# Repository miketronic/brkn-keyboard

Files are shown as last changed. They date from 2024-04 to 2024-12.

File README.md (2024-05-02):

# BR/KN
BR/KN Keyboard (Broken)




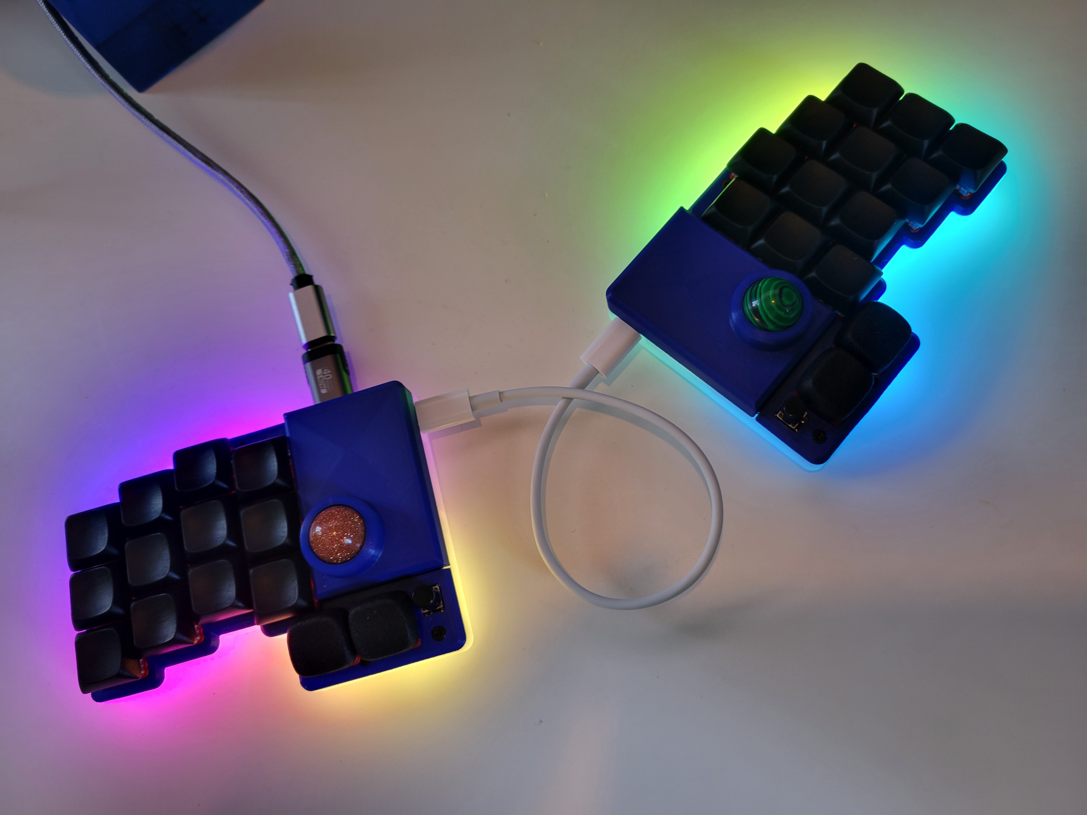
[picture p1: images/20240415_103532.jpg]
BR/KN 001

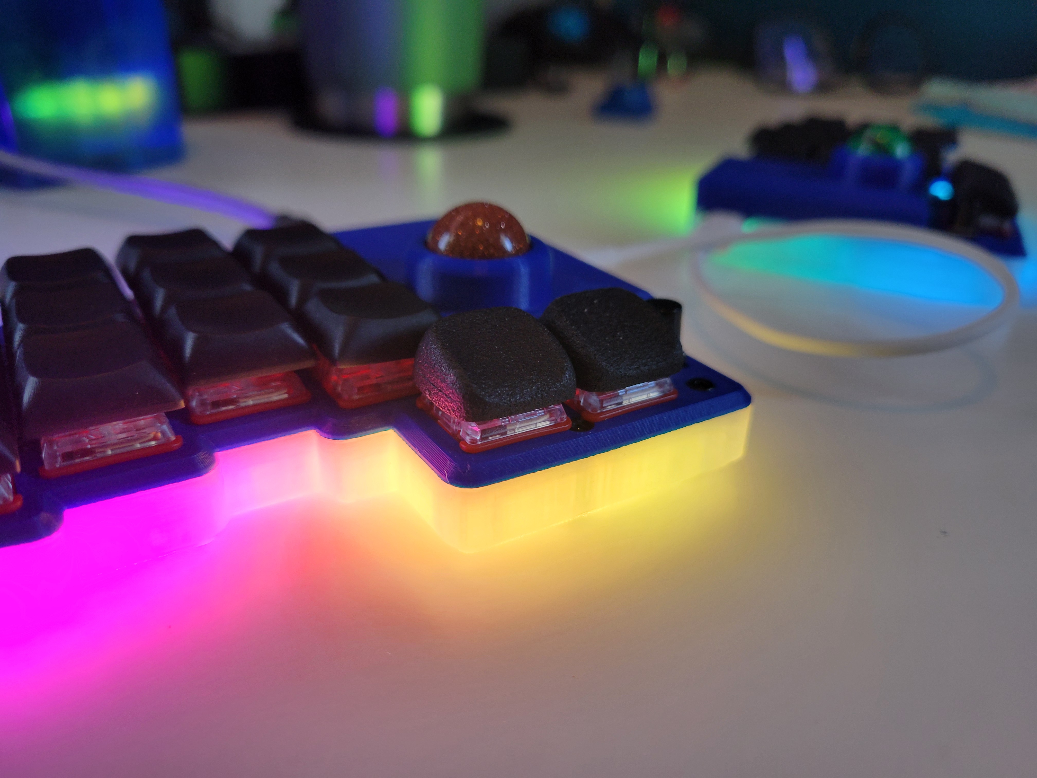
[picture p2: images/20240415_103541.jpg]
BR/KN 002


[More pictures here](images/)

## Features

- 28 keys (plus 2 small tactiles, bonus!)
- 2x 16mm trackballs - PMW3360 sensors
- USB connection between halves (or TRRS option as backup)
- Low profile choc switches with CFX spacing (closer spacing then standard choc, only caps of size 16.50mm x 16.50mm will fit)
- RGB lighting
- Waveshare RP2040 Zero controllers
- QMK firmware

## Introduction

The Broken (stylized BR/KN) keyboard is named because... 

  1. it's a split (a broken unibody)
  2. Broken by Seether was my wife and mine's wedding song that I wanted to honor and the day (queue awww's).  Ok enough on that, let's dig in.

I've always preferred small keebs and low switch counts.  The idea for this keyboard was to design a small split that also incorporated two trackballs (can use one for pointing, one for scrolling!), and have some other goodies like LEDs and tact switches for occasional needs like macros or toggling the RGB.

## Keymap

The layout is a larger rendition of my MM20 (3 column) layout with the addition of side columms.  I have no issues with my 20 key layout but it's a BIG change for users and having some keys like tab and backspace on dedicated keys can be convenient.  Of course with custom firmware you are not locked into any specific layout.  If you only want to combo 2 letters (24 non-thumb keys, 26 letters!), then that's totally fine.

The layout, MM28, leverages combos (the yellow letters shown below) for less-used letters, or where they "feel best".  I performed some studies on letter frequency in the English language and most common bigrams and trigrams to determine the letter placement. It kind of started off as Colemak from what I recall, maybe it's actually really different, I forgets.  P and B are weird, they both just barely made it to combos instead of their own letters even though I use them more often then I anticipated.  They could have gone somewhere like the U and W keys but with the frequency I use them I wanted them on my index and middle finger instead of putting all that work on my ring finger.

The biggest thing with starting a layout like this is to accept the fact that you'll start off at like 5wpm but your brain will take over and it'll become second nature eventually just like any other layout.  It's super fun and not making any lateral finger movements feels nice. 

br-kn

## Keycaps

As noted in the *Features*, I chose a narrower keyswitch spacing and thus they require narrower keycaps.  CFX keycaps are commercially available from Chosfox, or you can print your own, for which I've included files in the keycaps folder.  They easily print upside down on an FDM printer, and I use a textured baseplate.

## Miscellaneous Notes

- For the switchplate, I put the plate on then soldered the switches.  Make sure you like your choice of filament that you printed the plate with because you're stuck with it ;).
- If you PCBA the board and the USB failed during manufacture, you can solder on a TRRS connector.  I have it designed to mount the TRRS on the bottom of the board to hide the connector and end of the cable within the case.  Also, you'll need to bodge two wires on the board to use TRRS, let me know if you need help if you go this route.
- The trackballs I used are 16mm polished mineral spheres I found on AliExpress.  I picked up a few different types of mineral and some were too large due to making a rock into a sphere not an exact science, so be mindful of that.  Alternatively, you can use human-made materials for a perfect spec 16mm ball.
- PCBA would be cheaper if you combine both halves with some mouse bites between them, feel free to do so or modify as you wish.  I did this version as a POC so it was cheaper if I messed up with one board than with both at the same time.

## The predecessor (CAP 5)

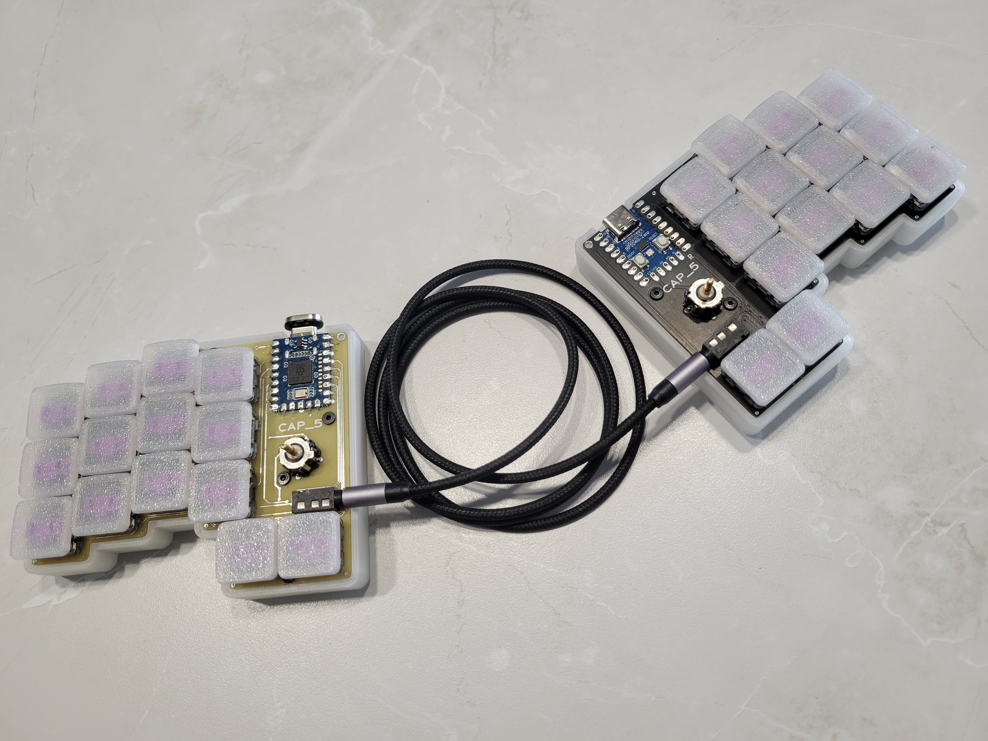
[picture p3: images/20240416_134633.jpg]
CAP5 001


[Another shot](images/20240416_134642.jpg)

Contact with comments, questions, or if you build it!
- m1ketronic @discord
- mxb540@gmail.com

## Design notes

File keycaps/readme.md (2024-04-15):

### Print these face down. They feel nicer with a textured build plate.

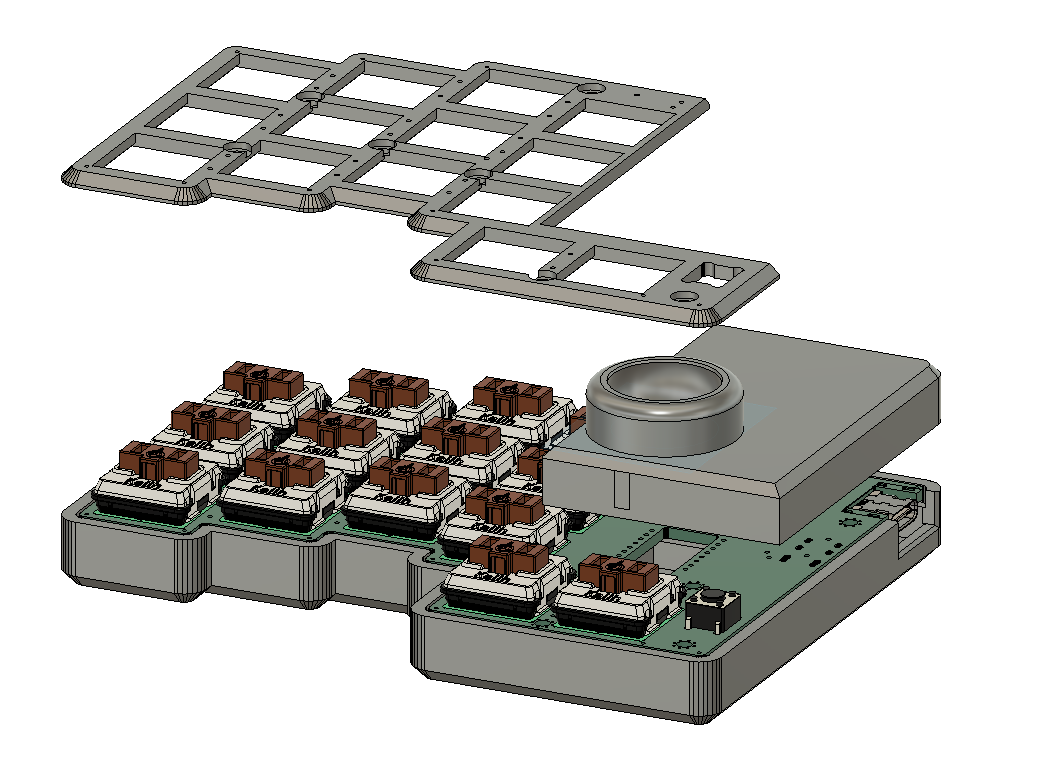
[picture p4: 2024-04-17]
images/brkn_guts.png

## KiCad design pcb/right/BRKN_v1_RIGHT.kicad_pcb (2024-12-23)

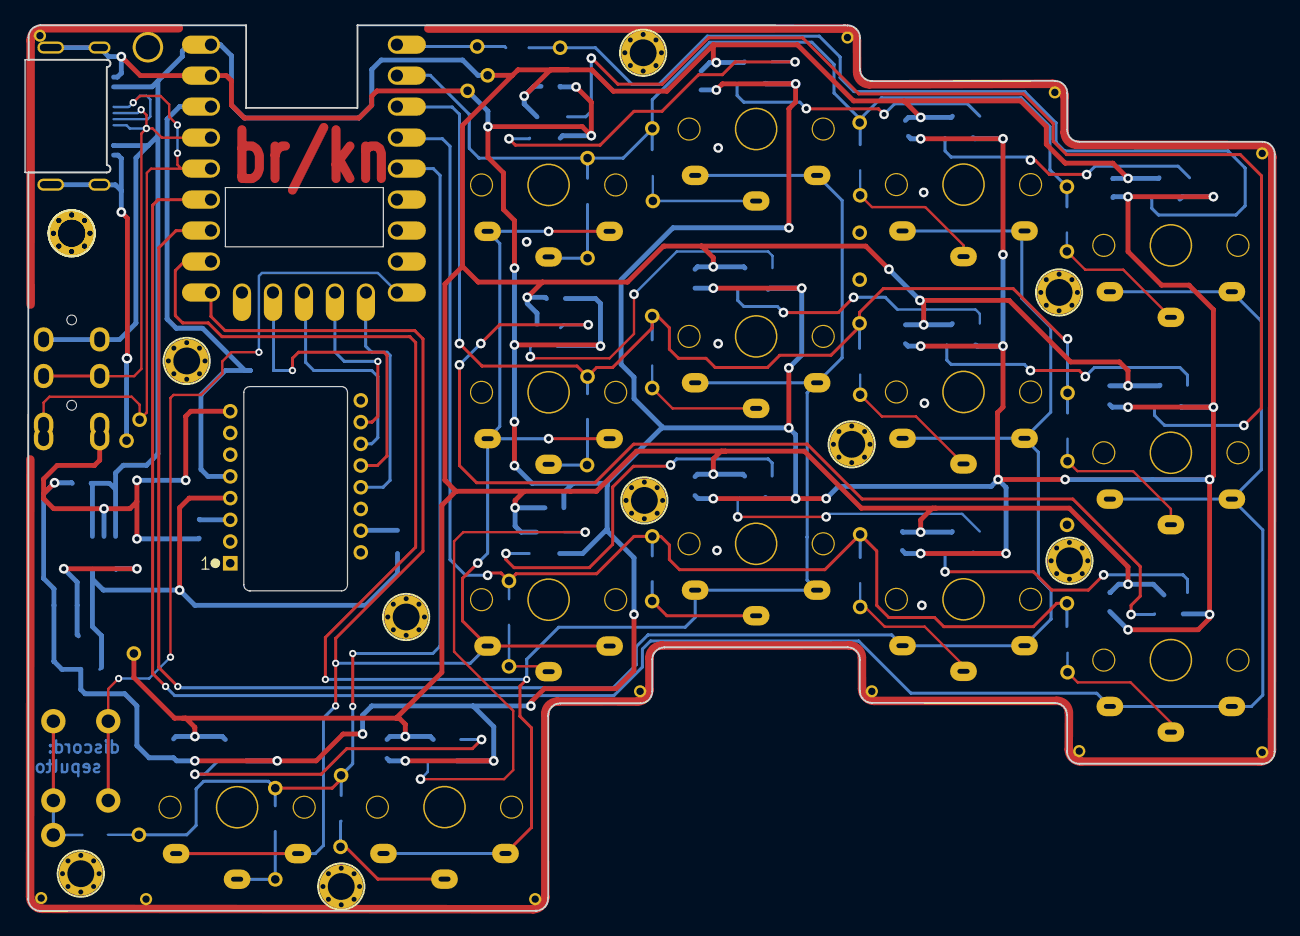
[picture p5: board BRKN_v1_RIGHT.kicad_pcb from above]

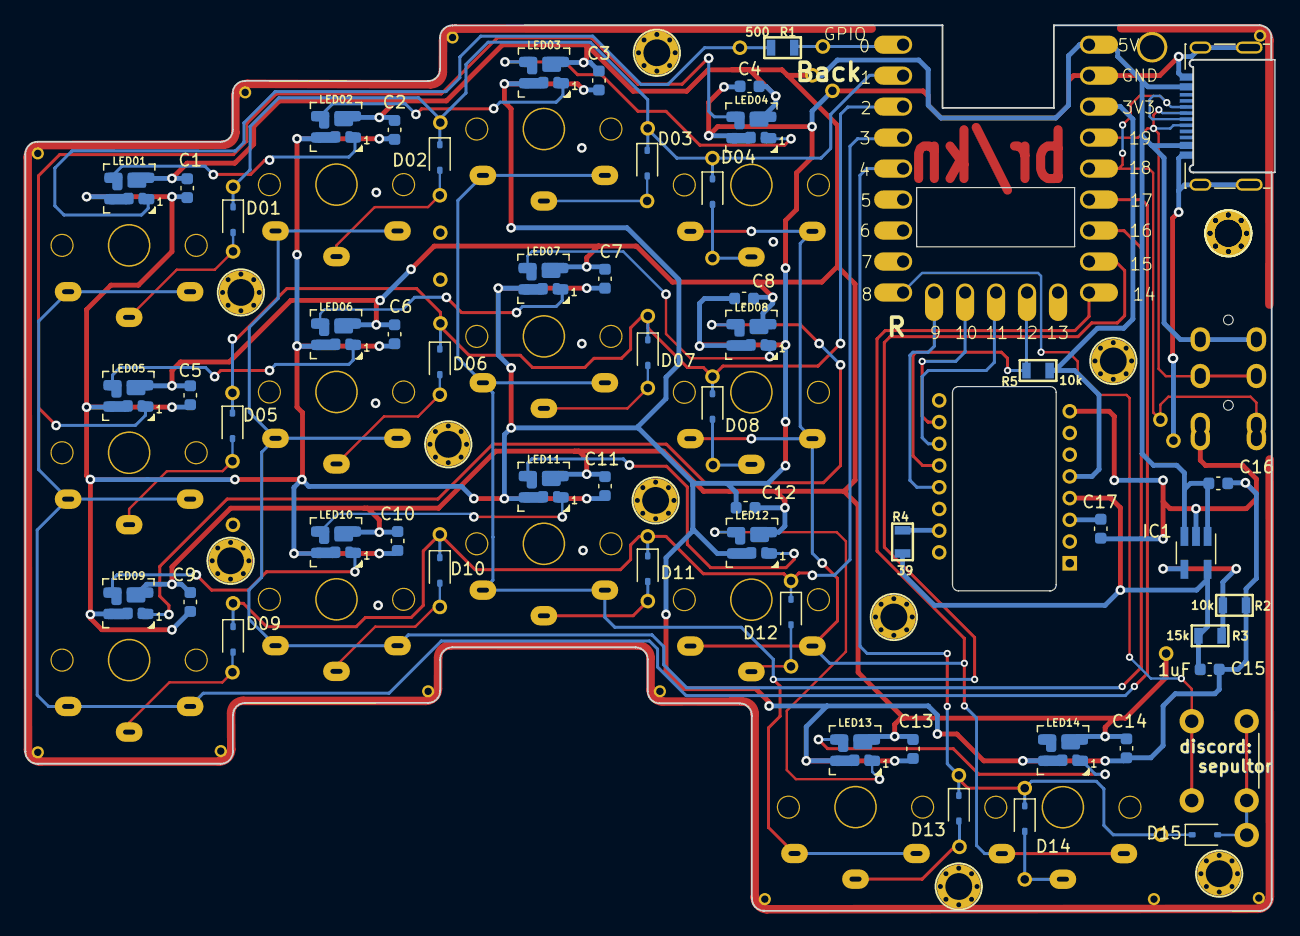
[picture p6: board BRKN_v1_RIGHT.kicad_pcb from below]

Board: 2 copper layers, 102.2 x 72.6 mm, 71 parts (69 on the bottom side), 52 nets.

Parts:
C1, C2, C3, C4, C5, C6, C7, C8, C9, C10, C11, C12, C13, C14, C15, C16: 1uF; C_0603_1608Metric
C17: 4.7uF; C_0603_1608Metric
D01, D02, D03, D04, D05, D06, D07, D08, D09, D10, D11, D12, D13, D14, D15: D; D_SOD-323
IC1: AP7335-WG-7; SOT-23-5_HandSoldering
J1: USB_C; MB_Molex-216990_USB_TYPE-C
LED01, LED02, LED03, LED04, LED05, LED06, LED07, LED08, LED09, LED10, LED11, LED12, LED13, LED14: SK6812MINI; MB_SK6812_Mini
R1: 500; R_0805
R2, R5: 10k; R_0805
R3: 15k; R_0805
R4: 39; R_0805
SW01, SW02, SW03, SW04, SW05, SW06, SW07, SW08, SW09, SW10, SW11, SW12, SW13, SW14: SW; MB_KailhChoc-1U_rev_17mm_oval
SW15: SW; MB_6x6_SW
U1: rp2040-zero; MB_rp2040-zero-001
U2: TRRS; MB_TRRS-PJ-320A
U3: PMW3360DM-T2QU; MB_PMW3360

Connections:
2V: C15.1, IC1.5 (OUT), R3.2, R4.1, U3.4 (VDD)
3V3: R5.1, U1.21 (3V3), U3.5 (VDDIO)
5V: C1.2, C2.2, C3.2, C4.2, C5.2, C6.2, C7.2, C8.2, C9.2, C10.2, C11.2, C12.2, C13.2, C14.2, C16.1, IC1.1 (IN), IC1.3 (EN), J1.A4 (VBUS), J1.A9 (VBUS), J1.B4 (VBUS), J1.B9 (VBUS), LED01.2 (VDD), LED02.2 (VDD), LED03.2 (VDD), LED04.2 (VDD), LED05.2 (VDD), LED06.2 (VDD), LED07.2 (VDD), LED08.2 (VDD), LED09.2 (VDD), LED10.2 (VDD), LED11.2 (VDD), LED12.2 (VDD), LED13.2 (VDD), LED14.2 (VDD), U1.23 (5V), U2.4 (RING2)
COL0: SW01.2, SW05.2, SW09.2, U1.18 (27)
COL1: SW02.2, SW06.2, SW10.2, U1.17 (26)
COL2: SW03.2, SW07.2, SW11.2, SW13.2, U1.16 (15)
COL3: SW04.2, SW08.2, SW12.2, SW14.2, U1.15 (14)
COL4: SW15.2, U1.9 (8)
GND: C1.1, C2.1, C3.1, C4.1, C5.1, C6.1, C7.1, C8.1, C9.1, C10.1, C11.1, C12.1, C13.1, C14.1, C15.2, C16.2, C17.2, IC1.2 (GND), J1.A1 (GND), J1.A12 (GND), J1.B1 (GND), J1.B12 (GND), J1.S1 (SHIELD), LED01.4 (VSS), LED02.4 (VSS), LED03.4 (VSS), LED04.4 (VSS), LED05.4 (VSS), LED06.4 (VSS), LED07.4 (VSS), LED08.4 (VSS), LED09.4 (VSS), LED10.4 (VSS), LED11.4 (VSS), LED12.4 (VSS), LED13.4 (VSS), LED14.4 (VSS), R2.2, U1.22 (GND), U2.1 (SLEEVE), U3.8 (GND)
LED: R1.1, U1.1 (0)
MISO: R5.2, U1.13 (12), U3.12 (MISO)
MOSI: U1.12 (11), U3.11 (MOSI)
NCS: U1.10 (9), U3.13 (NCS)
unnamed: D01.2, SW01.1
unnamed: D02.2, SW02.1
unnamed: D03.2, SW03.1
unnamed: D04.2, SW04.1
unnamed: D05.2, SW05.1
unnamed: D06.2, SW06.1
unnamed: D07.2, SW07.1
unnamed: D08.2, SW08.1
unnamed: D09.2, SW09.1
unnamed: D10.2, SW10.1
unnamed: D11.2, SW11.1
unnamed: D12.2, SW12.1
unnamed: D13.2, SW13.1
unnamed: D14.2, SW14.1
unnamed: D15.2, SW15.1
unnamed: IC1.4 (ADJ), R2.1, R3.1
unnamed: LED01.1 (DIN), R1.2
unnamed: LED01.3 (DOUT), LED02.1 (DIN)
unnamed: LED02.3 (DOUT), LED03.1 (DIN)
unnamed: LED03.3 (DOUT), LED04.1 (DIN)
unnamed: LED04.3 (DOUT), LED05.1 (DIN)
unnamed: LED05.3 (DOUT), LED06.1 (DIN)
unnamed: LED06.3 (DOUT), LED07.1 (DIN)
unnamed: LED07.3 (DOUT), LED08.1 (DIN)
unnamed: LED08.3 (DOUT), LED09.1 (DIN)
unnamed: LED09.3 (DOUT), LED10.1 (DIN)
unnamed: LED10.3 (DOUT), LED11.1 (DIN)
unnamed: LED11.3 (DOUT), LED12.1 (DIN)
unnamed: LED12.3 (DOUT), LED13.1 (DIN)
unnamed: LED13.3 (DOUT), LED14.1 (DIN)
unnamed: R4.2, U3.15 (LED_P)
unnamed: C17.1, U3.3 (VDDPIX)
ROW0: D01.1, D02.1, D03.1, D04.1, U1.2 (1)
ROW1: D05.1, D06.1, D07.1, D08.1, U1.3 (2)
ROW2: D09.1, D10.1, D11.1, D12.1, U1.4 (3)
ROW3: D13.1, D14.1, D15.1, U1.5 (4)
RX: J1.A7 (D-), J1.B7 (D-), U1.20 (29), U2.3 (RING1)
SCK: U1.11 (10), U3.10 (SCLK)
TX: J1.A6 (D+), J1.B6 (D+), U1.19 (28), U2.2 (TIP)

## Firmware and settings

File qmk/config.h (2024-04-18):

// Copyright 2024 
// miketronic@github sepultor@discord -- Mike B <mxb540@gmail.com>
// SPDX-License-Identifier: GPL-2.0+

#pragma once

#    define DEBOUNCE 7
#    define HOLD_ON_OTHER_KEY_PRESS
#    define HOLD_ON_OTHER_KEY_PRESS_PER_KEY
#    define TAPPING_TERM 170
#    define COMBO_TERM 150
#    define MACRO_TIMER 3

// Enable rapid switch from tap to hold, setting to 0 disables double tap hold auto-repeat.
#    define QUICK_TAP_TERM 0

#    define SPLIT_USB_DETECT
#    define USE_SERIAL
#    define SERIAL_USART_FULL_DUPLEX
#    define SERIAL_USART_TX_PIN GP28
#    define SERIAL_USART_RX_PIN GP29
#    define SERIAL_USART_PIN_SWAP
#    define MASTER_LEFT

// RGBLIGHT settings
// https://docs.qmk.fm/#/feature_rgblight
#    define WS2812_DI_PIN GP0
#    define WS2812_PIO_USE_PIO1
#    define RGBLIGHT_SPLIT
#    define RGBLED_NUM 28
#    define RGBLED_SPLIT { 14, 14 }
#    define RGBLIGHT_SLEEP

#    undef RGBLIGHT_DEFAULT_HUE
#    define RGBLIGHT_DEFAULT_HUE 43

#    define RGBLIGHT_HUE_STEP 8
#    define RGBLIGHT_SAT_STEP 8
#    define RGBLIGHT_VAL_STEP 5

#    undef RGBLIGHT_LIMIT_VAL
#    define RGBLIGHT_LIMIT_VAL 255
#    define RGBLIGHT_DEFAULT_VAL 80
#    define RGBLIGHT_DEFAULT_MODE RGBLIGHT_MODE_STATIC_LIGHT

#    define RGBLIGHT_EFFECT_BREATHING
#    define RGBLIGHT_EFFECT_KNIGHT
#    define RGBLIGHT_EFFECT_STATIC_GRADIENT
#    define RGBLIGHT_EFFECT_TWINKLE
#    undef RGBLIGHT_EFFECT_RAINBOW_MOOD
#    undef RGBLIGHT_EFFECT_RAINBOW_SWIRL
#    undef RGBLIGHT_EFFECT_SNAKE
#    undef RGBLIGHT_EFFECT_CHRISTMAS
#    undef RGBLIGHT_EFFECT_ALTERNATING


// SPI
#    define SPI_DRIVER SPID1
#    define SPLIT_POINTING_ENABLE
#    define POINTING_DEVICE_RIGHT
#    define POINTING_DEVICE_CS_PIN GP9
#    define SPI_SCK_PIN GP10
#    define SPI_MISO_PIN GP12
#    define SPI_MOSI_PIN GP11

// PMW3360 settings
//#    define PMW3360_CPI 12000
//#    define PMW3360_CS_DIVISOR 8
//#    define POINTING_DEVICE_TASK_THROTTLE_MS 10
#    define POINTING_DEVICE_ROTATION_180_RIGHT
#    define POINTING_DEVICE_INVERT_X_RIGHT
#    define POINTING_DEVICE_COMBINED
//#    define ROTATIONAL_TRANSFORM_ANGLE 97
//#    define MOUSE_EXTENDED_REPORT

// Mouse key speed and acceleration.
#    undef MOUSEKEY_DELAY
#    define MOUSEKEY_DELAY          0
#    undef MOUSEKEY_INTERVAL
#    define MOUSEKEY_INTERVAL       16
#    undef MOUSEKEY_WHEEL_DELAY
#    define MOUSEKEY_WHEEL_DELAY    0
#    undef MOUSEKEY_MAX_SPEED
#    define MOUSEKEY_MAX_SPEED      6
#    undef MOUSEKEY_TIME_TO_MAX
#    define MOUSEKEY_TIME_TO_MAX    64

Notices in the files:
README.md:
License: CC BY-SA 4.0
